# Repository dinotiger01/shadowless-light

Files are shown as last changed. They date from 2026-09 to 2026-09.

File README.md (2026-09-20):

# shadowless-light
## if you are a Stardance reviewer i messed up when doing the ship it has the wrong banner and video
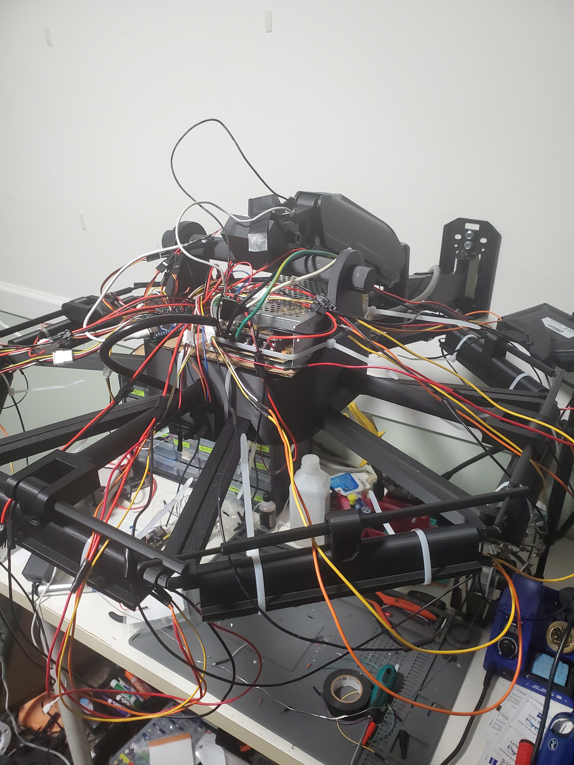
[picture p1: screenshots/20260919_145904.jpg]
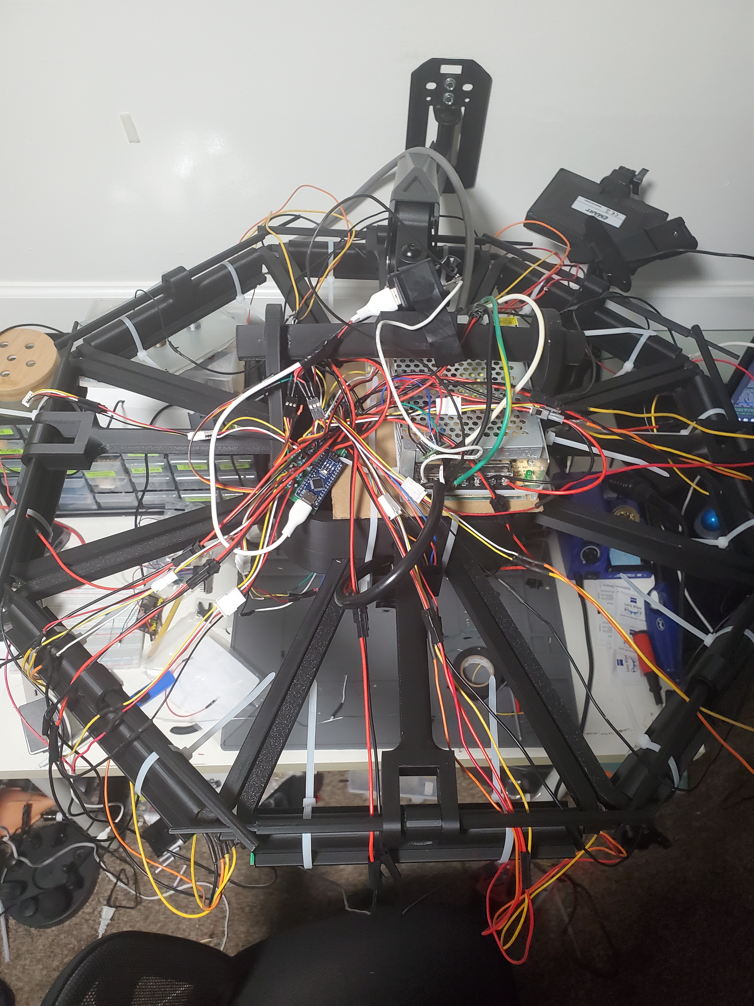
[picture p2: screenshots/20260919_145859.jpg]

***
## description
demo video: https://youtu.be/H-r51vnOVfs<br>
this is a desk light designed to not cast a shadow to make working on fine details easier<br>
it works by having a main light then there is octogon ring around it that has lights and will tilt in and out to make sure every spot has at least one light on it<br>

| regular light | shadowless ligh |
|---|---|
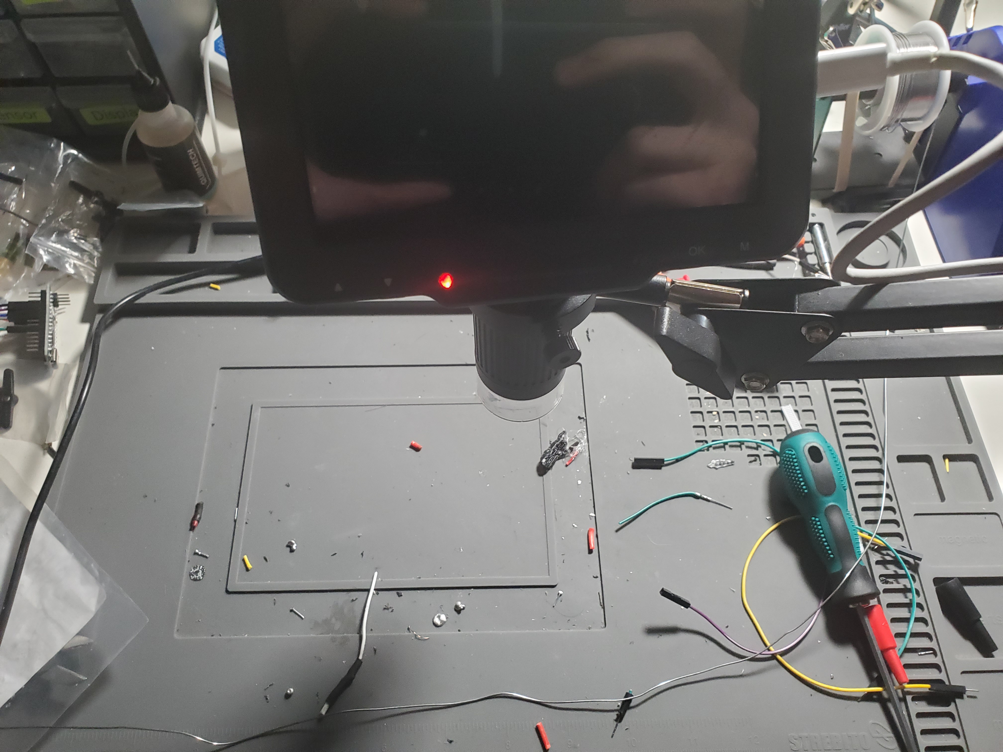
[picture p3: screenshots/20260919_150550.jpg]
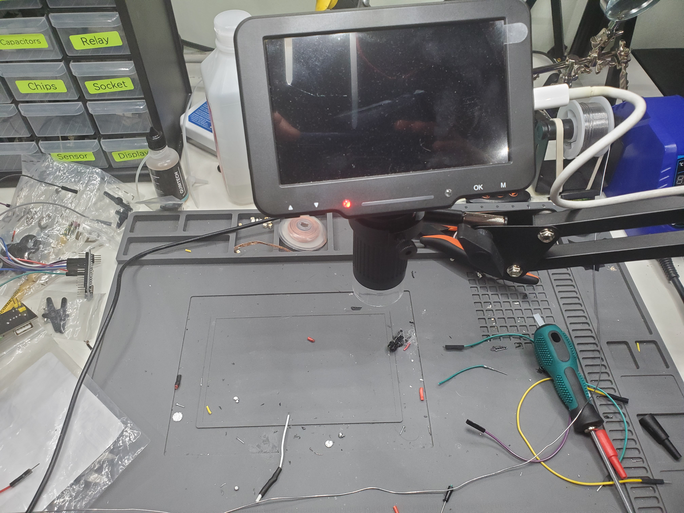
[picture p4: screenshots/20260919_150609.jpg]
|  |  

### use cases
* soldering
* painting fine detail
* just like any kinda of work tbh
### features
* btight
* RGBW
* UV
* adjustable lights
* blind yourself
## assembly
i cover this in the yt video a lot better
***
### 3d print
settings:<br>
plastic: pla<br>
supports: trees<br>
layer hight: 0.28mm<br>
nozzle: 0.4mm<br>
nozzle temp: 210°C<br>
bed temp: 60°C<br>
infill: 15%<br>

| number | name|
| --- | --- |
| 1 | hook |
| 1 | main |
| 16 | supports |
| 8 | light |
| 8 | pivoit |
| 8 | push |
| 4 | servo |
| 16 | pin |
| 1 | cover |
### wall 
attatch the stand to the wall the instructions are on the box
### 3d print assembly
* remove suports
* put the hook on stand
* place the main thing on the hook
* place all the 16 suports in the main thing and secure it with the pins
* thread the pivots throught the suports and the lights to make an octogon
* put the servos through the big holes in the main thing
* then thread the push through the top of the light and the servo
* then the goes on top of the main thing
### pcbs
| number | name |
|---|---|
| 8 | left wing |
| 8 | right wing  |
| 1 | main |
| 1 | indicator |
| 1 | motherboard |
### soldering 
350 c recomended
* solder the 1 left wing light
* solder the 1 right wing light
* use the pad on the side to hold them togeather
* solder wires to the sides of the pcb
* repeate x 8
* main board
  * RGBW the uv 
  * one of the lights needs some help
* mother board 
  * the v line is a cut power cable
* indicator
### arduino
you need to use adruino ide to upload the script to the arduino nano
### servos :(
so i forgot about the servo when making the pcb so there isnt a convinent break out for it so
you need to solder a wire to pin 7 directly then split the wire in to 4 then thats the data wire for the servos and the gnd and power come direcly from the power suply
also i think my servos are too weak so they wernt able to actualy do anyyhing
### assembling electronics
* wings
  * zip tie just like every thing
  * then do that 8 times
* main
  * you guesed it zip ties
* plug in all the things
* power supply
  * connect a 120v ac up to the main thing
  * connect one side to the switch on the front and the other side to one on the things on the 12v rectifer
  * this is another thing i forgot to add to the pcb connect the 12v output to the power wires on the mother board
  * now for the 5v if you have a buck dc to dc converter use that i didnt so i did this
  * connect a wall 5v rectifyer in parralel with the 120vac then plug that in to the the arduino with a usb to usbc
  * however we need to cut this wire then split it in to a bunch of things so that we can power the servos
## documantation
* schemadic 
  * indicator this is used to show if it is on and what value you are adjusting
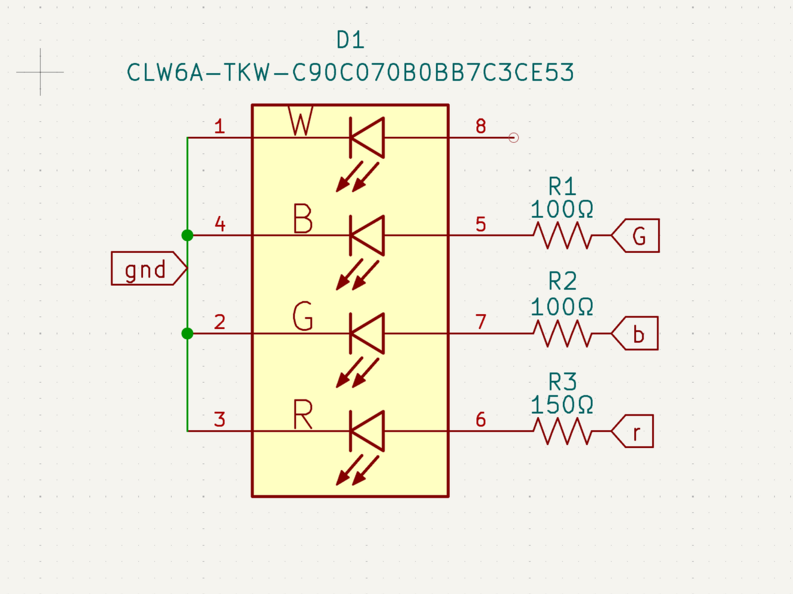
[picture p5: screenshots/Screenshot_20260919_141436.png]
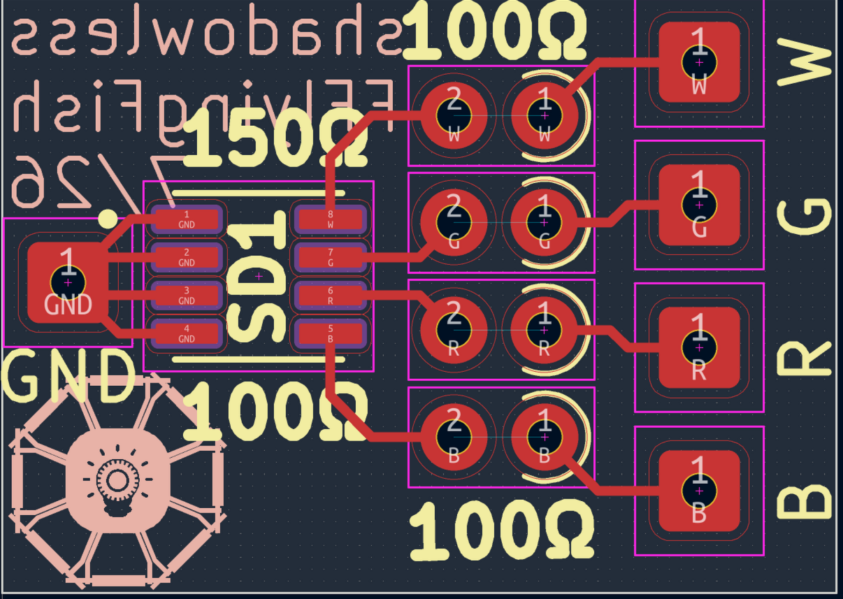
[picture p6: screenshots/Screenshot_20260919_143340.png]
  * 
  * right wing 
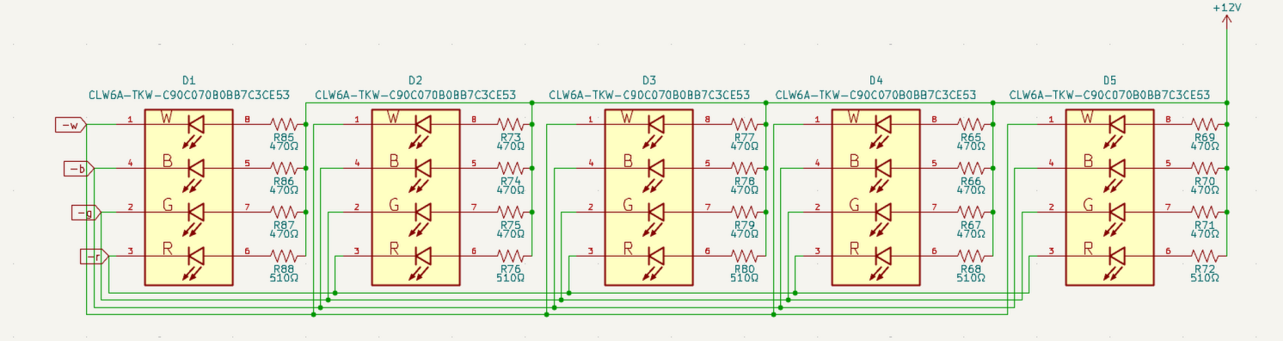
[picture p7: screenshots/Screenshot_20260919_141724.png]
  * 
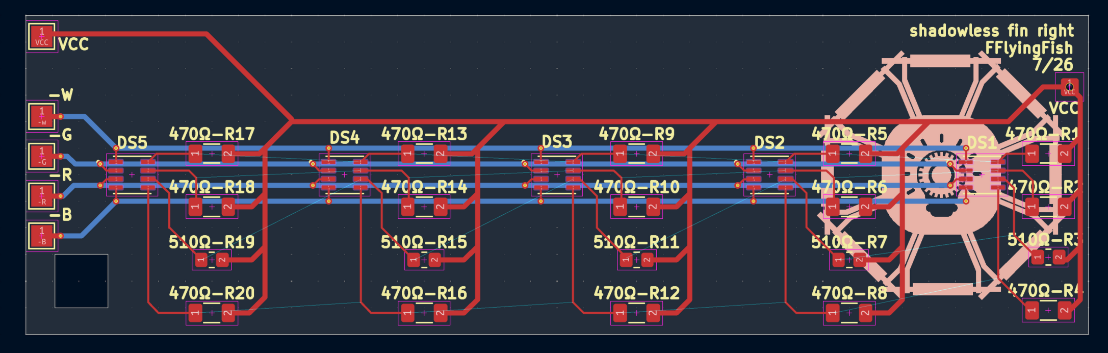
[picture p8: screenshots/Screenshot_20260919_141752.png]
  * 
  * left wing
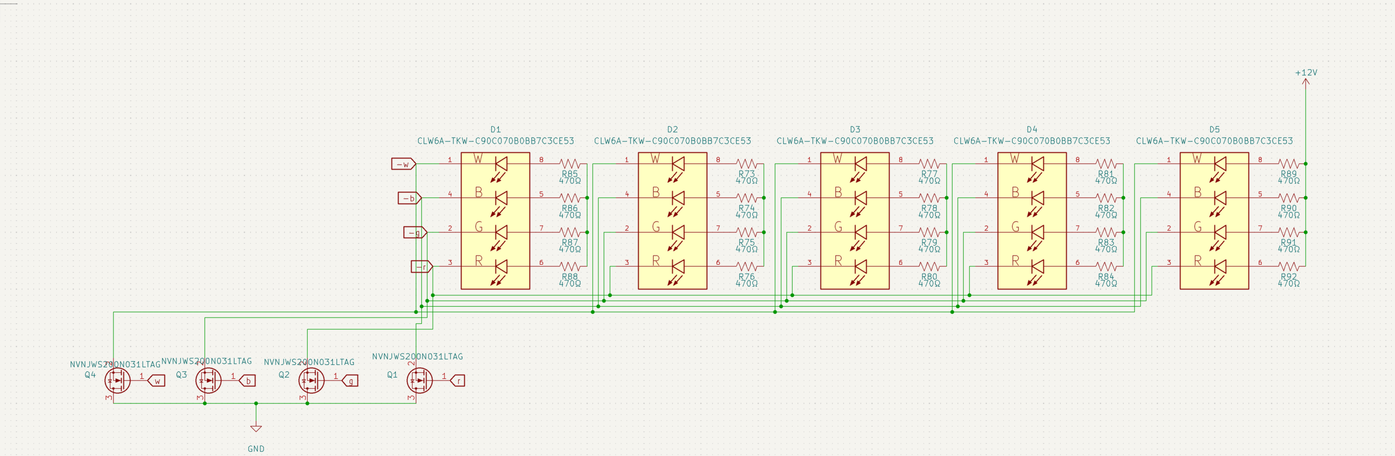
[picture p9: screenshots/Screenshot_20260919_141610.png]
  * 
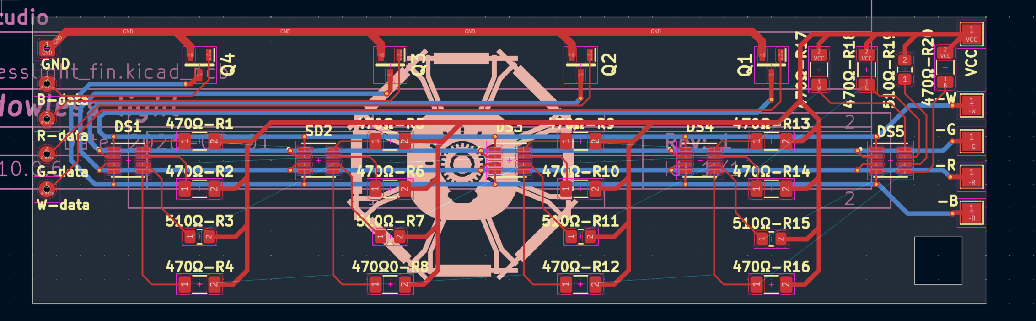
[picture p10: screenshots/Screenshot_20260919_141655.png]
  * 
  * motherboard
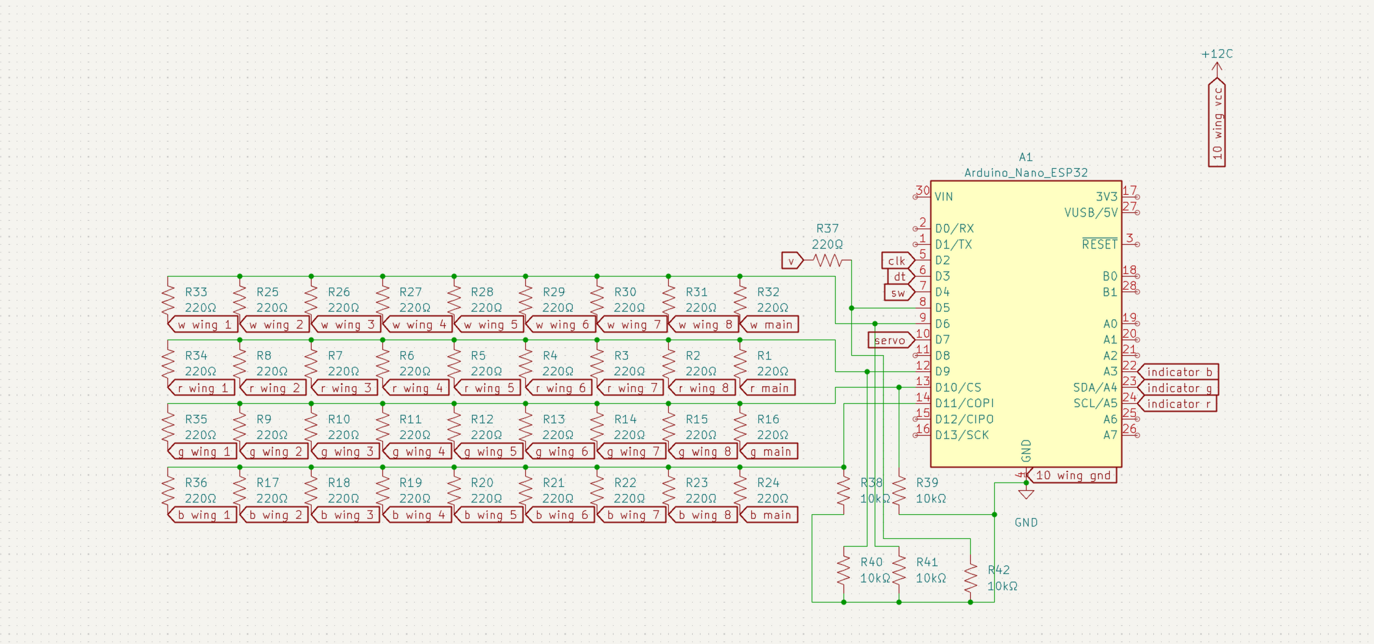
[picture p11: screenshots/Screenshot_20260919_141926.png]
  * 
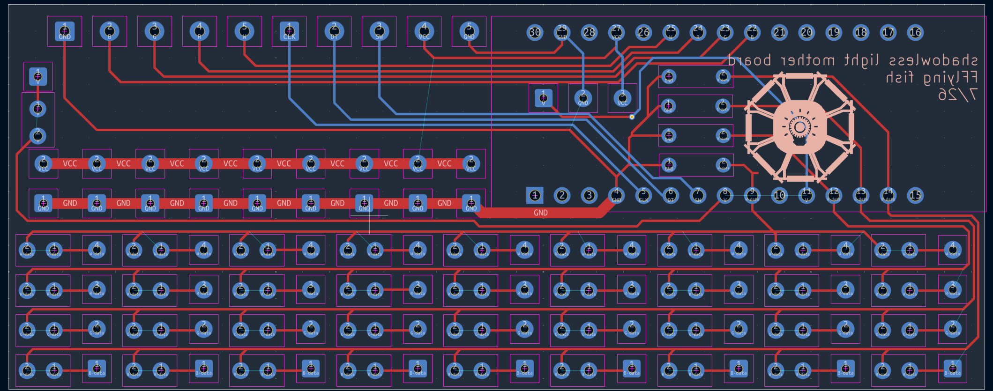
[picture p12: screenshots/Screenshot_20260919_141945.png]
  * 
  * main
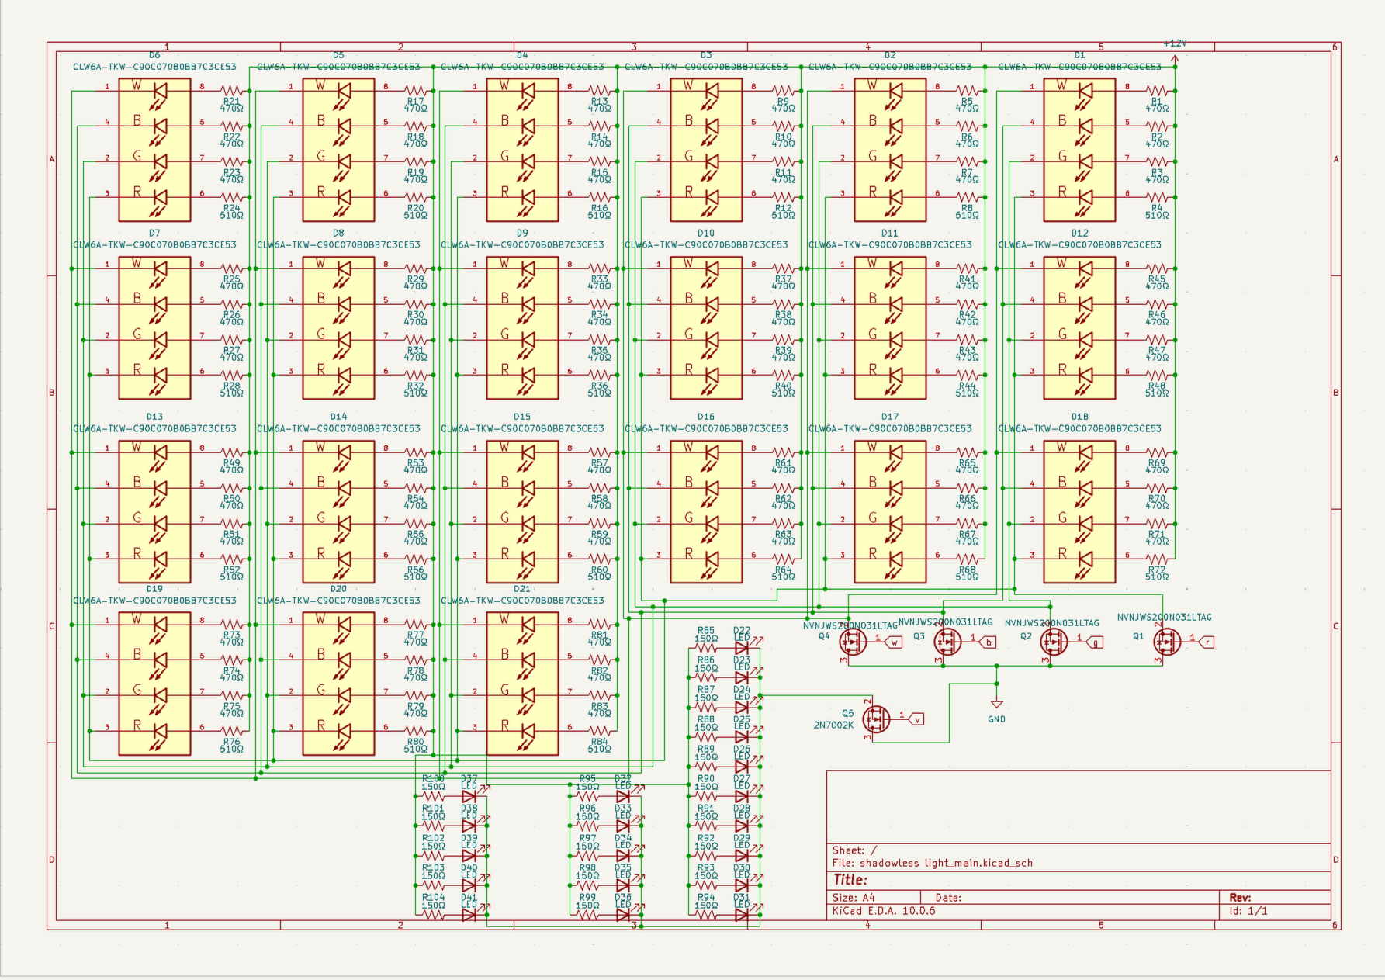
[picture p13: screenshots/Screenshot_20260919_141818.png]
  * 
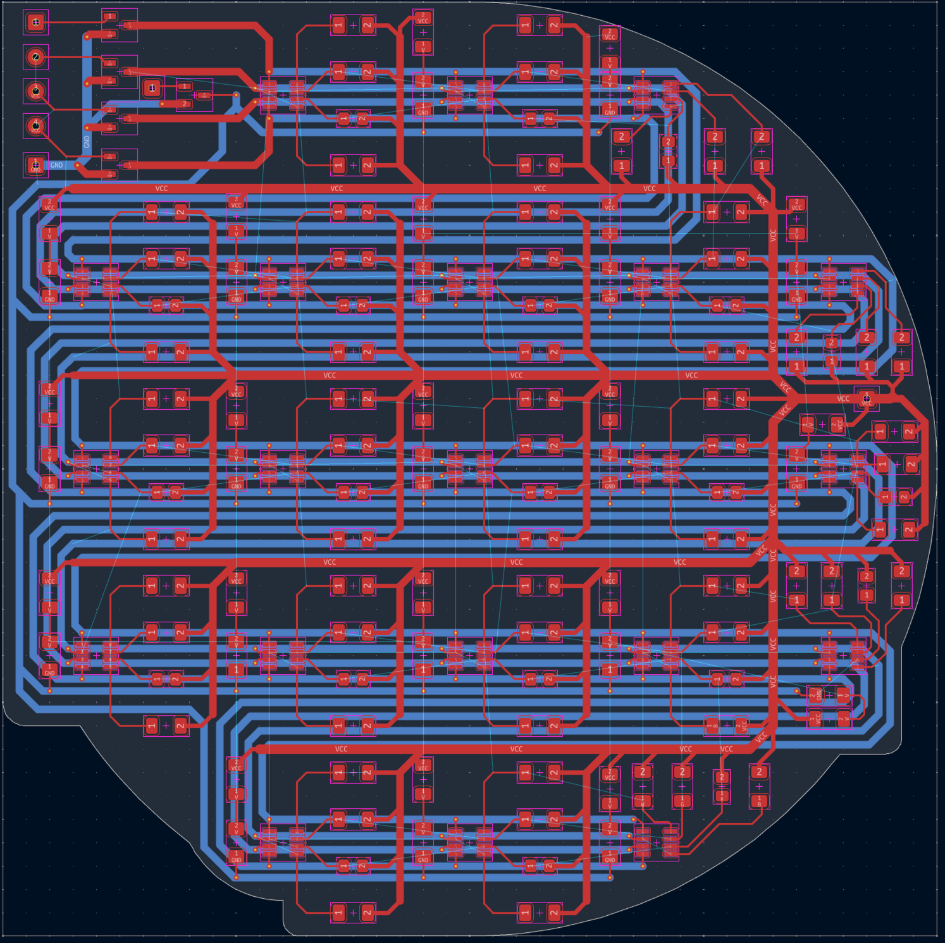
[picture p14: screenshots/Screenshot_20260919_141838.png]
  * 
* voltage stuff
  * lights are running at 12v 
  * each light runs at 20mA there is 4 lights in eash light there are 101 lights so 404 individual light + the 20 uv lights all run at 20mA or 0.02A * 424 = 8.48A
  * the 12 has 10A to cover it all
* lumins alot
  * red 4.8 lumens
  * green 10.7 lumens
  * blue 2.2 lumens
  * 10.7 lumens
  * 28.4 lumens per light X 101 = 248.4 lumens at max britness 
* it is suposed to sit about 600mm off your desk
* its about 600mm in total witch ngl i think is too big i might make a smaler one in the futger
## extra
* i am like really bad ar soldering so like half the light dont work

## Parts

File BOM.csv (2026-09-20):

NAME | QUANTITY | PRICE | LINK
nano | 1 | $25 | https://store-usa.arduino.cc/products/arduino-nano
power supply 12v | 1 | $12 | https://www.amazon.com/dp/B010CVIW7E?lv=shuf&channelId=704&plpRedirect=mhFallback
power supply 5v | 1 | $7 | https://www.amazon.com/Charger-TePoo-Adapter-Charging-Samsung/dp/B08LKKWNMB
solder | 1 | $13 | https://www.amazon.com/dp/B076QF1Y85?lv=shuf&channelId=425&plpRedirect=mhFallback&th=1
4pin JST | 9 | $9 | https://www.amazon.com/dp/B0DPJBGLJN?lv=shuf&channelId=425&plpRedirect=mhFallback&th=1
2pin JST | 11 | $11 | https://www.amazon.com/dp/B0C725395C?lv=shuf&channelId=425&plpRedirect=mhFallback
wall mount | 1 | $27 | https://www.amazon.com/dp/B0BP9MLV8X?lv=shuf&channelId=425&plpRedirect=mhFallback
150ohm smd | 20 | $5 | https://www.amazon.com/dp/B08R8FR3X7?lv=shuf&channelId=704&plpRedirect=mhFallback
UV lights | 20 | $6 | https://www.amazon.com/dp/B01CUGA0CE?lv=shuf&channelId=425&plpRedirect=mhFallback&th=1
WRGB light | 101 | $40 | https://www.mouser.com/en/ProductDetail/941-CLW6ATKWC90C0723
mosfet | 37 | $17 | https://www.mouser.com/en/ProductDetail/781-SI2300DS-T1-GE3
510ohm resistor smd | 101 | $10 | https://www.mouser.com/en/ProductDetail/71-CRCW0805510RFKEAH
470ohm resistor smd | 303 | $7 | https://www.mouser.com/en/ProductDetail/279-CRGCQ1206F470R
220ohm resistor tht | 37 | $5 | https://www.amazon.com/California-JOS-Resistance-CJ50-004-220/dp/B0BDKQSZHM
10kohm resistor tht | 5 | $4.https://www.amazon.com/California-JOS-Resistance-CJ50-004-220/dp/B0BDKY8VQG
wires you need a lot of wires
about $30 of plastic i used PLA
pcbs were like $40
total: 268

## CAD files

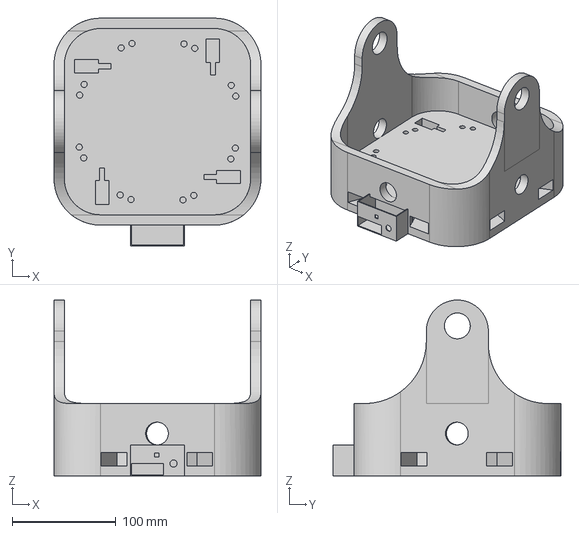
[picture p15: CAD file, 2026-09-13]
3d models/step/shadowless_main.step
200.0 x 220.0 x 170.0 mm

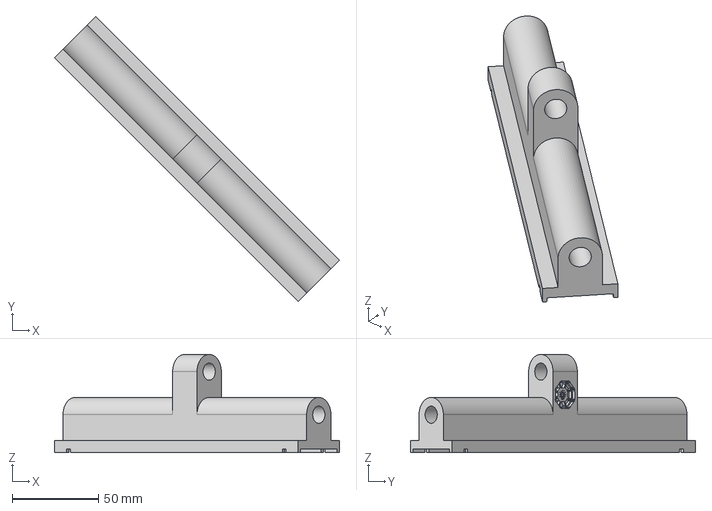
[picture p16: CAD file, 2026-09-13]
3d models/step/shadowless_light.step
165.5 x 165.5 x 57.0 mm

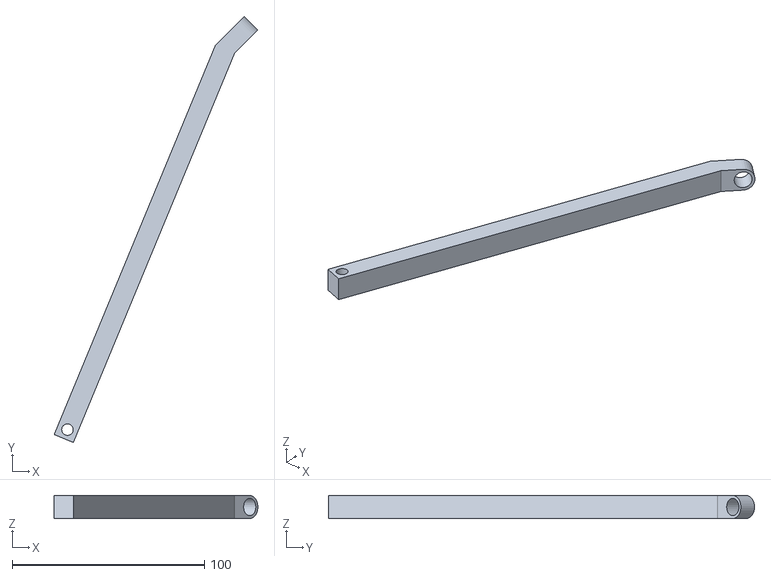
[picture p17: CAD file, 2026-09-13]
3d models/stl/shadowless_support.stl
105.9 x 221.5 x 12.0

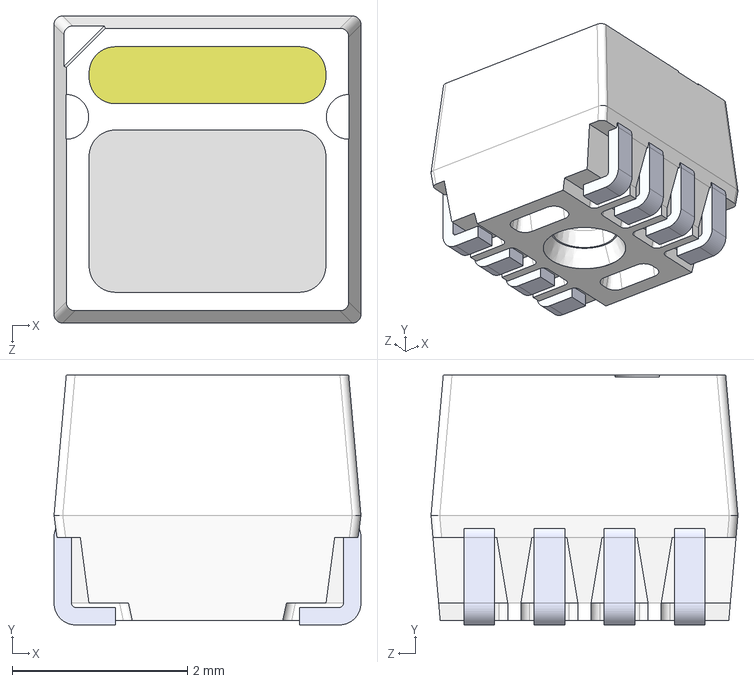
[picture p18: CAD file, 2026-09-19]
pcb/kicad/imported footprints/CLW6A-TKW-C90C070B0BB7C3CE53/CLW6A-TKW-C90C070B0BB7C3CE53.step
3.50 x 2.85 x 3.50 mm

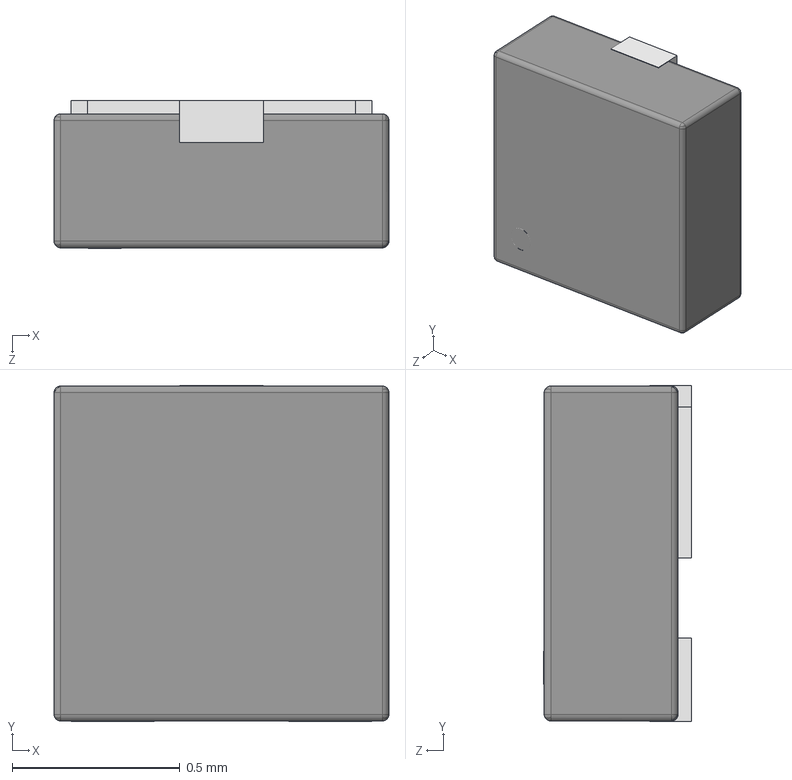
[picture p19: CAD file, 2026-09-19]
pcb/kicad/imported footprints/LIB_NVNJWS200N031LTAG/NVNJWS200N031LTAG/3D/NVNJWS200N031LTAG.stp
1.00 x 1.00 x 0.442 mm

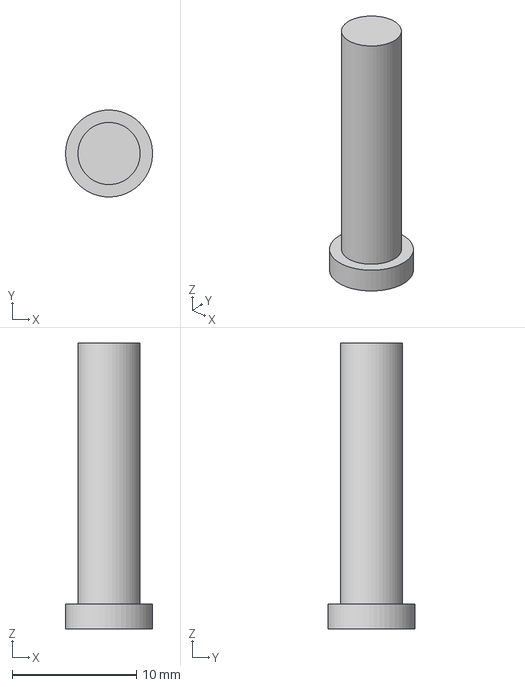
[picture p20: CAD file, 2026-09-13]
3d models/step/shadowless_pin.step
6.99 x 7.00 x 23.0 mm

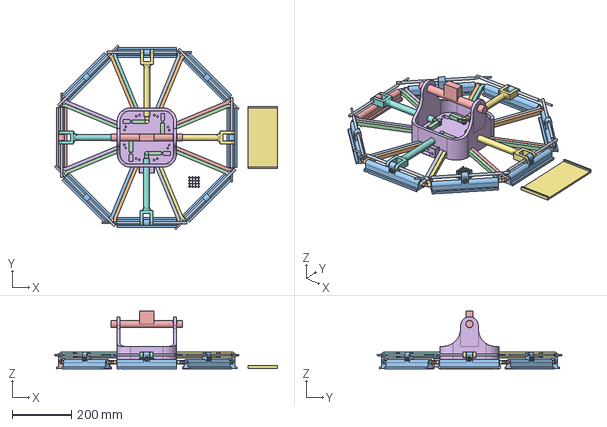
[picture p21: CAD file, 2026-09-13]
3d models/step/shadowless_all.step
750.8 x 621.6 x 195.1 mm

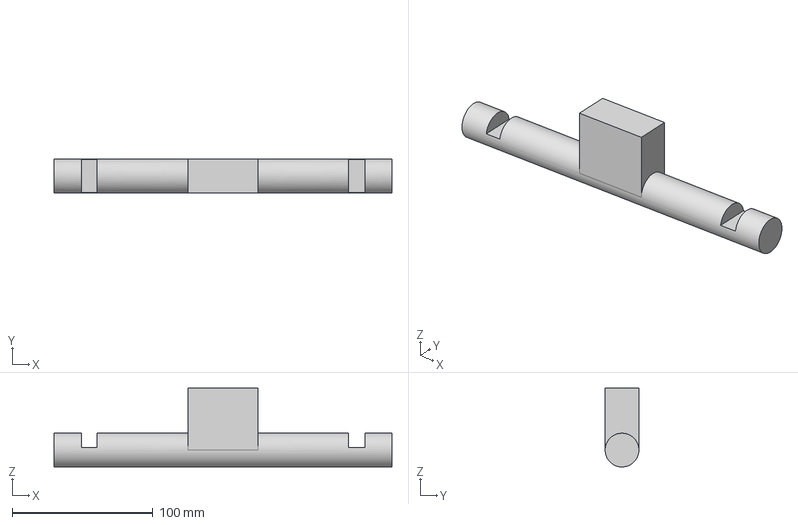
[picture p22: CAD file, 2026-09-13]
3d models/step/shadowless_hook.step
240.0 x 24.0 x 56.1 mm

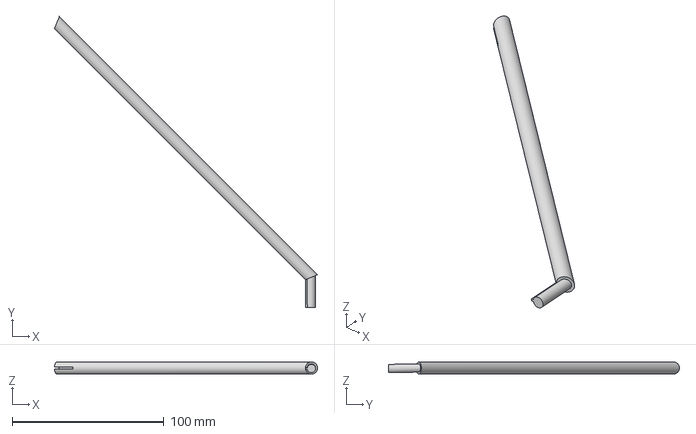
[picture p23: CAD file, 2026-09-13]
3d models/step/shadowless_pivot.step
173.5 x 191.8 x 8.00 mm

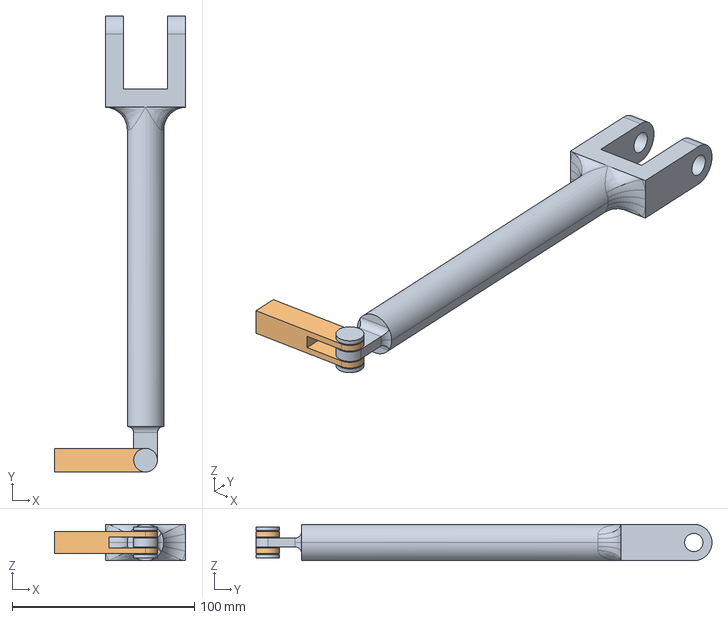
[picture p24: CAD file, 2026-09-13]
3d models/step/shadowless_servo.step
72.0 x 250.0 x 20.0 mm

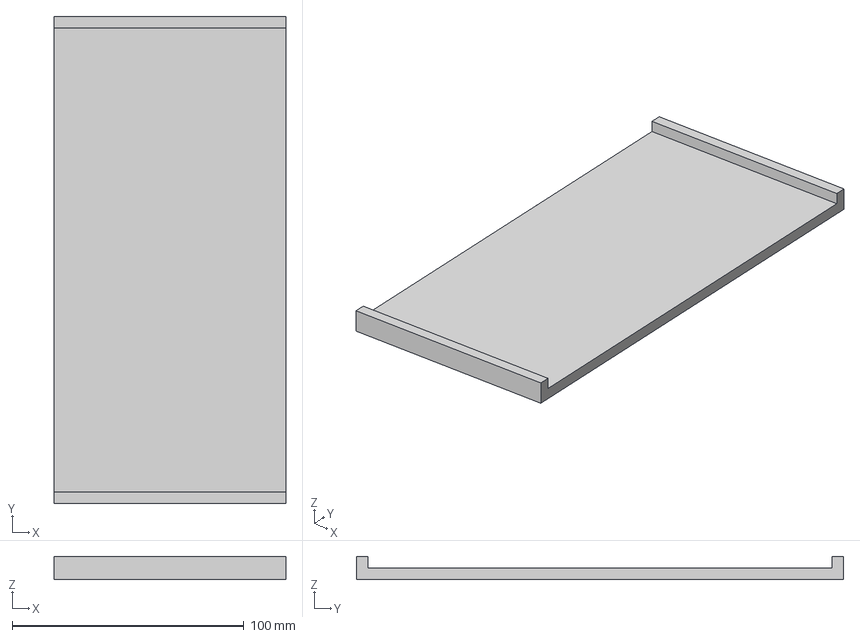
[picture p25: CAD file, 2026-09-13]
3d models/step/shadowless_cover.step
100.0 x 210.0 x 10.0 mm

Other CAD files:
3d models/shadowless_all.f3d
3d models/stl/shadowless_all.stl
3d models/stl/shadowless_cover.stl
3d models/stl/shadowless_hook.stl
3d models/stl/shadowless_light.stl
3d models/stl/shadowless_main.stl
3d models/stl/shadowless_pin.stl
3d models/stl/shadowless_pivot.stl
3d models/stl/shadowless_servo.stl

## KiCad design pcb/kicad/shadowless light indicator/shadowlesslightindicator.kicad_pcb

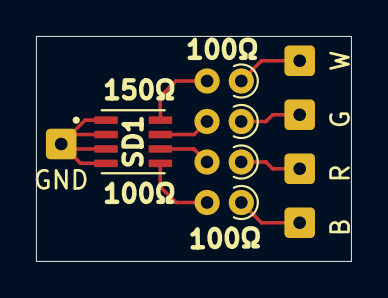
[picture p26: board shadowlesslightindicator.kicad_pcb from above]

Board: 2 copper layers, 17.5 x 12.5 mm, 10 parts (0 on the bottom side), 5 nets.

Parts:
100Ω, 100Ω#2, 100Ω#3, 150Ω: R_Axial_DIN0204_L3.6mm_D1.6mm_P1.90mm_Vertical
B: SolderWire-0.127sqmm_1x01_D0.48mm_OD1mm
G: SolderWire-0.127sqmm_1x01_D0.48mm_OD1mm
GND: SolderWire-0.127sqmm_1x01_D0.48mm_OD1mm
R: SolderWire-0.127sqmm_1x01_D0.48mm_OD1mm
SD1: LED_CLW6A_RGBW
W: SolderWire-0.127sqmm_1x01_D0.48mm_OD1mm

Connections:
B: 100Ω#2.1, 100Ω#2.2, SD1.5, W.1
G: 150Ω.1, 150Ω.2, R.1, SD1.7
GND: GND.1, SD1.1, SD1.2, SD1.3, SD1.4
R: 100Ω.1, 100Ω.2, G.1, SD1.6
W: 100Ω#3.1, 100Ω#3.2, B.1, SD1.8

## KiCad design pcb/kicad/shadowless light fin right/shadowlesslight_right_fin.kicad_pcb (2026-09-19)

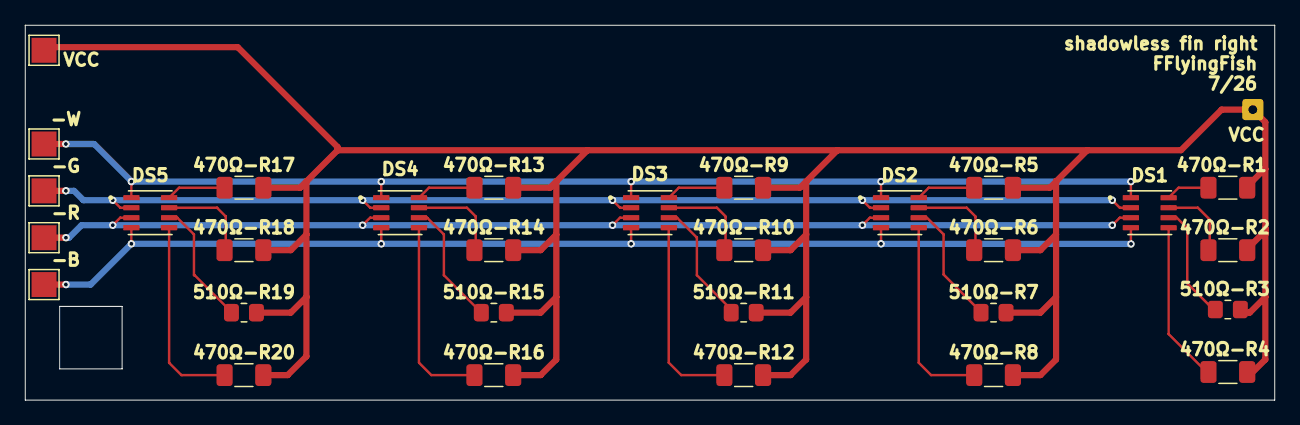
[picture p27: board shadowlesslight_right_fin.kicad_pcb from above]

Board: 2 copper layers, 100.0 x 30.0 mm, 31 parts (0 on the bottom side), 9 nets.

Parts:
470Ω-R1, 470Ω-R2, 470Ω-R4, 470Ω-R5, 470Ω-R6, 470Ω-R8, 470Ω-R9, 470Ω-R10, 470Ω-R12, 470Ω-R13, 470Ω-R14, 470Ω-R16, 470Ω-R17, 470Ω-R18, 470Ω-R20: R_1206_3216Metric_Pad1.30x1.75mm_HandSolder
510Ω-R3, 510Ω-R7, 510Ω-R11, 510Ω-R15, 510Ω-R19: R_0805_2012Metric_Pad1.20x1.40mm_HandSolder
-B: TestPoint_Pad_2.0x2.0mm
-G: TestPoint_Pad_2.0x2.0mm
-R: TestPoint_Pad_2.0x2.0mm
-W: TestPoint_Pad_2.0x2.0mm
DS1, DS2, DS3, DS4, DS5: LED_CLW6A_RGBW
VCC: SolderWire-0.127sqmm_1x01_D0.48mm_OD1mm
VCC#2: TestPoint_Pad_2.0x2.0mm

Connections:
-B: -B.1, DS1.4, DS2.4, DS3.4, DS4.4, DS5.4
-G: -G.1, DS1.2, DS2.2, DS3.2, DS4.2, DS5.2
-R: -R.1, DS1.3, DS2.3, DS3.3, DS4.3, DS5.3
-w: -W.1, DS1.1, DS2.1, DS3.1, DS4.1, DS5.1
B: DS1.5, DS2.5, DS3.5, DS4.5, DS5.5
G: DS1.7, DS2.7, DS3.7, DS4.7, DS5.7
R: DS1.6, DS2.6, DS3.6, DS4.6, DS5.6
VCC: VCC.1, VCC#2.1
W: DS1.8, DS2.8, DS3.8, DS4.8, DS5.8

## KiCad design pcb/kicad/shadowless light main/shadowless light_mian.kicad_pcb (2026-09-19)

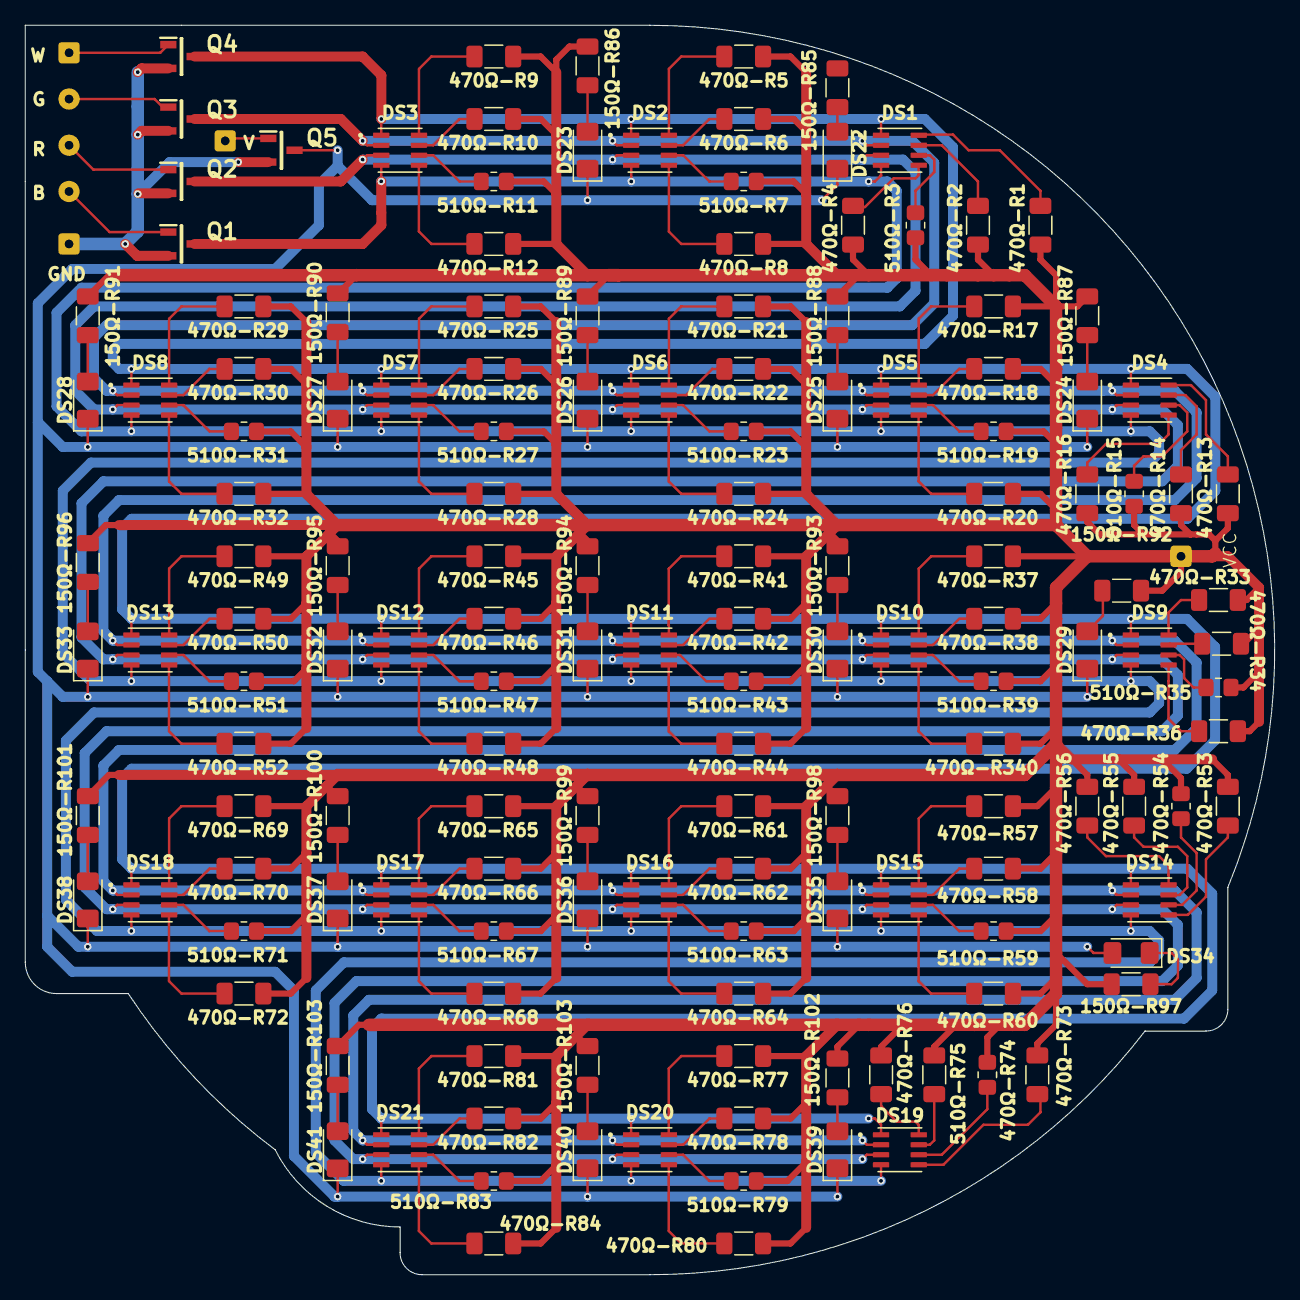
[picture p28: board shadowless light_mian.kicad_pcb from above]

Board: 2 copper layers, 100.0 x 100.0 mm, 65 parts (0 on the bottom side), 11 nets.

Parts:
150Ω-R85, 150Ω-R86, 150Ω-R87, 150Ω-R88, 150Ω-R89, 150Ω-R90, 150Ω-R91, 150Ω-R92, 150Ω-R93, 150Ω-R94, 150Ω-R95, 150Ω-R96, 150Ω-R97, 150Ω-R98, 150Ω-R99, 150Ω-R100, 150Ω-R101, 150Ω-R103, 150Ω-R103#2: R_1206_3216Metric_Pad1.30x1.75mm_HandSolder
DS1, DS2, DS4, DS4#2, DS5, DS6, DS7, DS8, DS11, DS11#2, DS12, DS12#2, DS13, DS15, DS16, DS17, DS17#2, DS18, DS19, DS20, DS21: LED_CLW6A-RGBW
DS22, DS23, DS24, DS25, DS26, DS27, DS28, DS29, DS30, DS31, DS32, DS33, DS34, DS35, DS36, DS37, DS38, DS39, DS40, DS41: LED_1206_3216Metric_Pad1.42x1.75mm_HandSolder
Q1, Q2, Q3, Q4, Q5: SOT95P237X112-3N

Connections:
-B: DS1.2, DS1.4, DS2.4, DS4.4, DS4#2.4, DS5.4, DS6.4, DS7.4, DS8.4, DS11.4, DS11#2.4, DS12.4, DS12#2.4, DS13.4, DS15.4, DS16.4, DS17.4, DS17#2.4, DS19.4, DS20.4, DS21.4, Q1.3
-G: DS2.2, DS4.2, DS4#2.2, DS5.2, DS6.2, DS7.2, DS8.2, DS11.2, DS11#2.2, DS12.2, DS12#2.2, DS13.2, DS15.2, DS16.2, DS17.2, DS17#2.2, DS19.2, DS20.2, DS21.2, Q3.3
-R: DS1.3, DS2.3, DS4.3, DS4#2.3, DS5.3, DS6.3, DS7.3, DS8.3, DS11.3, DS11#2.3, DS12.3, DS12#2.3, DS13.3, DS15.3, DS16.3, DS17.3, DS17#2.1, DS17#2.3, DS19.3, DS20.3, DS21.3, Q2.3
-W: DS1.1, DS2.1, DS4.1, DS4.8, DS4#2.1, DS5.1, DS6.1, DS7.1, DS8.1, DS11.1, DS11#2.1, DS12.1, DS12#2.1, DS13.1, DS15.1, DS16.1, DS17.1, DS19.1, DS20.1, DS21.1, Q4.3
B: DS1.5, DS2.5, DS4.5, DS4.7, DS4#2.5, DS5.5, DS6.5, DS7.5, DS8.5, DS11.5, DS11#2.5, DS12.5, DS12#2.5, DS15.5, DS16.5, DS17.5, DS17#2.5, DS19.5, DS20.5, DS21.5
G: DS1.7, DS2.7, DS4#2.7, DS5.7, DS6.7, DS7.7, DS8.7, DS11.7, DS11#2.7, DS12.7, DS12#2.7, DS15.7, DS16.7, DS17.7, DS17#2.7, DS19.7, DS20.7, DS21.7
GND: DS17.6, DS22.1, DS23.1, DS24.1, DS25.1, DS26.1, DS27.1, DS28.1, DS29.1, DS30.1, DS31.1, DS32.1, DS33.1, DS34.2, DS38.1, DS39.1, DS40.1, DS41.1, Q1.2, Q2.2, Q3.2, Q4.2, Q5.3
R: DS1.6, DS2.6, DS4.6, DS4#2.6, DS5.6, DS6.6, DS7.6, DS8.6, DS11.6, DS11#2.6, DS12.6, DS12#2.6, DS15.6, DS16.6, DS17#2.6, DS19.6, DS20.6, DS21.6
V: 150Ω-R85.1, 150Ω-R86.1, 150Ω-R87.1, 150Ω-R88.1, 150Ω-R89.1, 150Ω-R90.1, 150Ω-R91.1, 150Ω-R92.1, 150Ω-R93.1, 150Ω-R94.1, 150Ω-R95.1, 150Ω-R96.1, 150Ω-R97.2, 150Ω-R98.1, 150Ω-R99.1, 150Ω-R100.1, 150Ω-R101.1, 150Ω-R103.1, 150Ω-R103#2.1, DS22.2, DS23.2, DS24.2, DS25.2, DS26.2, DS27.2, DS28.2, DS29.2, DS30.2, DS31.2, DS32.2, DS33.2, DS34.1, DS35.2, DS36.2, DS37.2, DS38.2, DS39.2, DS40.2, DS41.2
VCC: 150Ω-R85.2, 150Ω-R86.2, 150Ω-R87.2, 150Ω-R88.2, 150Ω-R89.2, 150Ω-R90.2, 150Ω-R91.2, 150Ω-R92.2, 150Ω-R93.2, 150Ω-R94.2, 150Ω-R95.2, 150Ω-R96.2, 150Ω-R97.1, 150Ω-R98.2, 150Ω-R99.2, 150Ω-R100.2, 150Ω-R101.2, 150Ω-R103.2, 150Ω-R103#2.2, DS21.8, Q1.1, Q2.1, Q3.1
W: DS1.8, DS2.8, DS4#2.8, DS5.8, DS6.8, DS7.8, DS8.8, DS11.8, DS11#2.8, DS12.8, DS12#2.8, DS15.8, DS16.8, DS17.8, DS17#2.8, DS19.8, DS20.8

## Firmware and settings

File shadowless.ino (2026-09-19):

// #include <Servo.h>
#include <ServoTimer2.h>
// rotary endoder
#define rot_clk 2
#define rot_dt 3
#define rot_sw 4
// each color brighness
int countW = 0;
int countR = 0;
int countG = 0;
int countB = 0;
int servAng = 1500;
// rot stuff
int current;
int last;
int type = 0;

int vPin = 5;
int wPin = 6;
int rPin = 9;
int gPin = 10;
int bPin = 11;

int indB = A3;
int indG = A4;
int indR = A5;

unsigned long lastServoPulse = 0;
unsigned long buttonDebounceTimer = 0;

int servoPin = 7;

void setup(){
  pinMode(wPin, OUTPUT);
  pinMode(rPin, OUTPUT);
  pinMode(gPin, OUTPUT);
  pinMode(bPin, OUTPUT);
  pinMode(vPin, OUTPUT);
  pinMode(indB, OUTPUT);
  pinMode(indG, OUTPUT);
  pinMode(indR, OUTPUT);
  pinMode(servoPin, OUTPUT);
  

  pinMode(rot_clk, INPUT_PULLUP);
  pinMode(rot_dt, INPUT_PULLUP);
  pinMode(rot_sw, INPUT_PULLUP);

  Serial.begin(9600);

  last = digitalRead(rot_clk);

  analogWrite(indR, 255);
  analogWrite(indG, 255);
  analogWrite(indB, 255);
}

void loop(){
  if (millis() - lastServoPulse >= 20) {
    digitalWrite(servoPin, HIGH);
    delayMicroseconds(servAng); // Precise servo pulse length
    digitalWrite(servoPin, LOW);
    lastServoPulse = millis();
  }
  current = digitalRead(rot_clk);
  if(current != last && current == LOW){
    if(digitalRead(rot_dt) != current){
      if(type == 0 && countW < 255){
        countW += 5;
      }else if(type == 1 && countR < 255){
        countR += 5;
        Serial.println(countR);
      }else if(type == 2 && countG < 255){
        countG += 5;
      }else if(type == 3 && countB < 255){
        countB += 5;
      }else if(type == 4 && servAng < 2250){
        servAng += 5;
      }
      //clockwise
    }else{
      //counter clockwise
      if(type == 0 && countW > 0){
        countW -= 5;
      }else if(type == 1 && countR > 0){
        countR -= 5;
        Serial.println(countR);
      }else if(type == 2 && countG > 0){
        countG -= 5;
      }else if(type == 3 && countB > 0){
        countB -= 5;
      }else if(type == 4 && servAng > 750){
        servAng -= 5;
      }
    }
    analogWrite(wPin, countW);
    analogWrite(rPin, countR);
    analogWrite(gPin, countG);
    analogWrite(bPin, countB);

    // myServ.write(servAng);
    Serial.println(servAng);
  }
  last = current;


  if(digitalRead(rot_sw) == LOW && (millis() - buttonDebounceTimer > 300)){
    buttonDebounceTimer = millis();
    type++;
    if(type == 6){ 
      type = 0;
    }
    
    if(type == 0){
      analogWrite(vPin, 0);
      digitalWrite(indR, HIGH); digitalWrite(indG, HIGH); digitalWrite(indB, HIGH);
    }else if(type == 1){
      analogWrite(vPin, 0);
      digitalWrite(indR, HIGH); digitalWrite(indG, LOW); digitalWrite(indB, LOW);
    }else if(type == 2){
      analogWrite(vPin, 0);
      digitalWrite(indR, LOW); digitalWrite(indG, HIGH); digitalWrite(indB, LOW);
    }else if(type == 3){
      analogWrite(vPin, 0);
      digitalWrite(indR, LOW); digitalWrite(indG, LOW); digitalWrite(indB, HIGH);
    }else if(type == 4){
      analogWrite(vPin, 0);
      digitalWrite(indR, HIGH); digitalWrite(indG, HIGH); digitalWrite(indB, LOW);
    }else if(type == 5){
      analogWrite(vPin, 255);
      digitalWrite(indR, HIGH); digitalWrite(indG, LOW); digitalWrite(indB, HIGH);
    }
  }
}
